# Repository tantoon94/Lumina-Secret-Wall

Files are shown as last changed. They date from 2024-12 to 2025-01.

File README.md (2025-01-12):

# Lumina-Secret-Wall
This project is designed for the [CASA0014 Connected Environments](https://github.com/ucl-casa-ce/casa0014) module to build an IoT device to control The [Chrono Lumina](https://github.com/ucl-casa-ce/casa0014/tree/main/chronoLumina) LED lights at CASA, UCL, through an MQTT broker. This Wall is an IoT device that can control the Chrono Lumina via six LDR sensors placed inside six projected hexagons. The nodes on each hexagon correspond to the placement of six LED numbers on Chrono Lumina. By Shedding light on any hexagon's LDR sensor (with any kind of flashlight), six corresponding LEDs will light up five showing the intensity of the flashlight using a gradient of cold to warm colours and one only white indicating a piece of code to decipher. The wall's final code could be deciphered by identifying the coloured LED numbers and putting them together in order. 

<p align="center">
The Fabricated Lumina wall
</p>

## Components

1. MCU Board (Arduino MKR 1010)
2. Sensors (LDR MJ5549)
7. Resistors (1kΩ for controlling the LDR sensitivity)
8. Breadboard (for prototyping)
9. Jumper Wires (male-to-male and male-to-female)
10 Power Supply (5V power supply is sufficient, Barrel Jack)

## Libraries
Make sure to include the following libraries in your Arduino IDE:

1. WiFiNINA
2. PubSubClient

## The project GuideMap

 The schematic model for devopling the device based on Chrono Lumina can be helpful in understanding the posisioning of the LEDs. Furthermore, it can be used to understand the Arrays defined in the code. To test the code without publishing to the broker, use the latest [Test](https://github.com/tantoon94/Lumina-Secret-Wall/blob/main/Arduino_Sketch/Test_sun_6pm/Test_sun_6pm.ino) version using the Arduino serial terminal to for debugging. 
<p align="center">
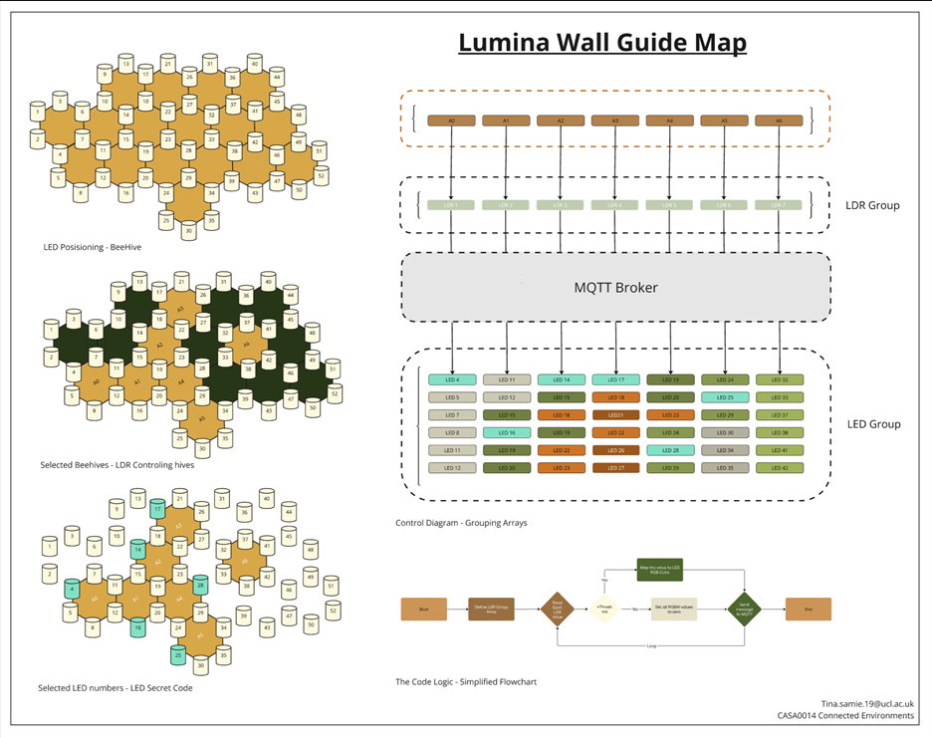
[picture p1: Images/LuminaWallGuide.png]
The Lumina Wall Guide

</p>

## Setup Instructions

### Circuit Connections:
1. **Power Supply:**
   - Connect the `3.3V` pin on the MKR 1010 to the positive rail on the breadboard.
   - Connect the `GND` pin on the MKR 1010 to the negative rail on the breadboard.

2. **LDR and Resistor Setup:**
   - For each LDR, connect one end to the positive rail (`3.3V`).
   - Connect the other end of each LDR to one end of a `10-ohm` resistor.
   - Connect the other end of each `10-ohm` resistor to the negative rail (`GND`).

3. **Analog Input Connections:**
   - Connect the junction between each LDR and its corresponding `10-ohm` resistor to an analog input pin on the MKR 1010 (e.g., `A0`, `A1`, `A2`, etc.).

<p align="center">
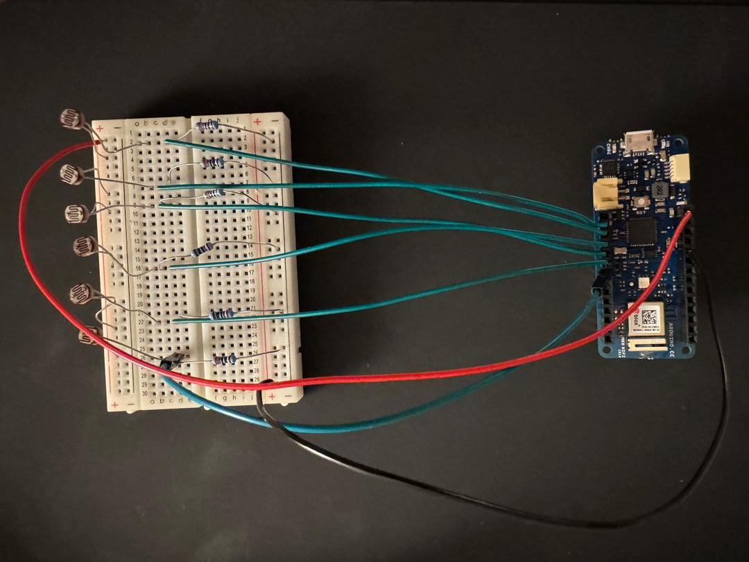
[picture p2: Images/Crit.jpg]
The Fabricated Lumina wall
  
</p>

### Design
 Using the [Model](https://github.com/tantoon94/Lumina-Secret-Wall/tree/main/MODEL) folder you can access the 3D models of the project. 
 The [G-code](https://github.com/tantoon94/Lumina-Secret-Wall/tree/main/MODEL/3Dprint/G-code) for the printing settings are available in the same directory. 

**MQTT Broker and LED Control:**
- Utilized an MQTT broker to publish instructions for controlling the color and on/off status of each LED pixel (12 pixels per LED string).
- Controlled 6 LEDs with one LDR using a matrix array to hold each LED number and their respective pixels.
- Managed simultaneous messages to shared LEDs, prioritizing messages where the threshold was crossed.
- Ensured LEDs turned off when below the threshold.
 
### Limitations 

**Sensor Calibration:**
- Calibrating sensors for varying light conditions was challenging.
- Using a `10Ω` resistor reduced the sensors' sensitivity, helping distinguish between environmental and flashlight light.
- Designed hexagon modular shapes with a three-pointed star crack to minimize environmental light while allowing sufficient flashlight light.
- Aimed to find the perfect balance between too much and too little light.

##  Contact Details

Tina Samie: tina.samie.19@ucl.ac.uk

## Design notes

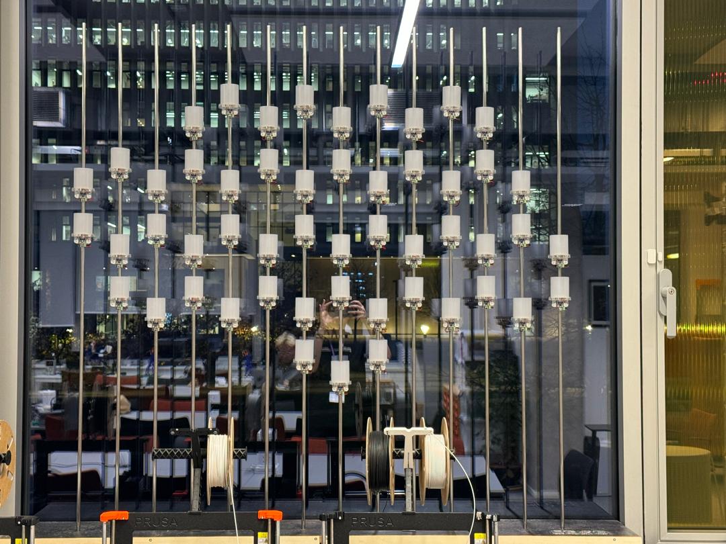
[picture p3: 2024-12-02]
Images/ChronoLumina.jpg

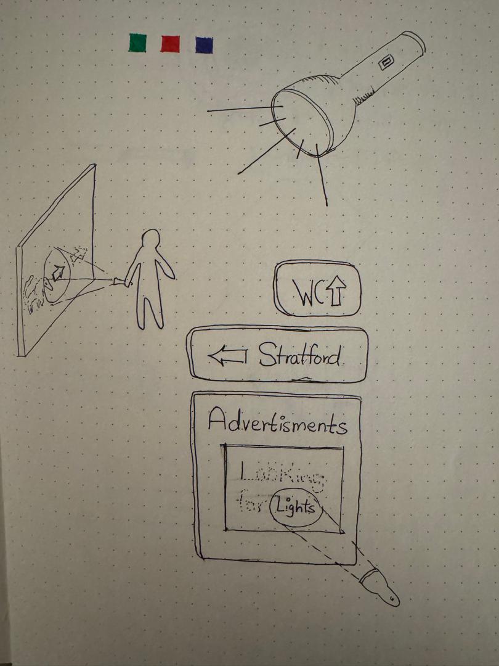
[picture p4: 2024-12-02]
Images/Sketch-Idea-1.jpg

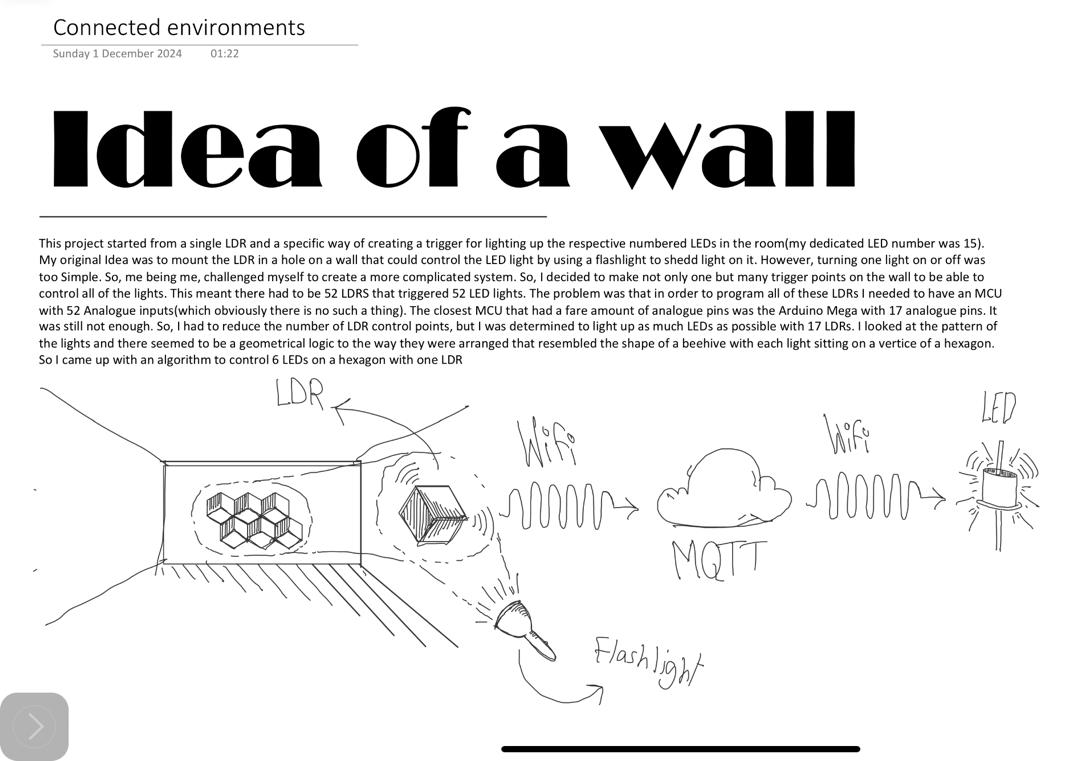
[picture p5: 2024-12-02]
Images/Sketch-Idea-2.jpg

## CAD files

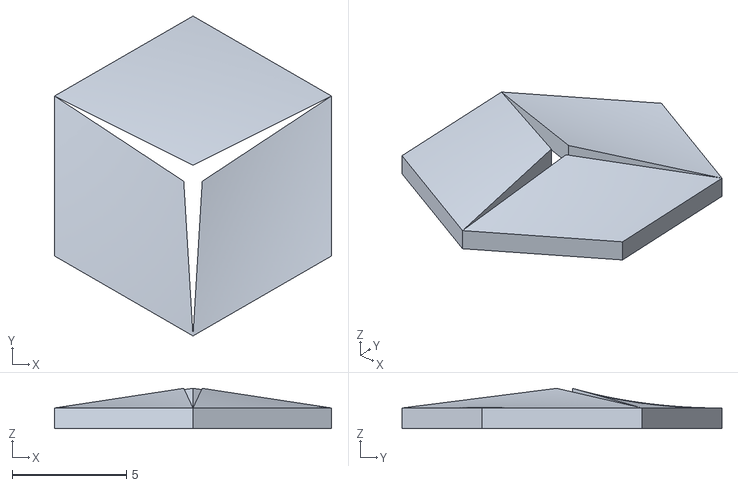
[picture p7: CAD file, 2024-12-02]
MODEL/3Dprint/Sample_02_mesh.stl
12.1 x 14.0 x 1.77

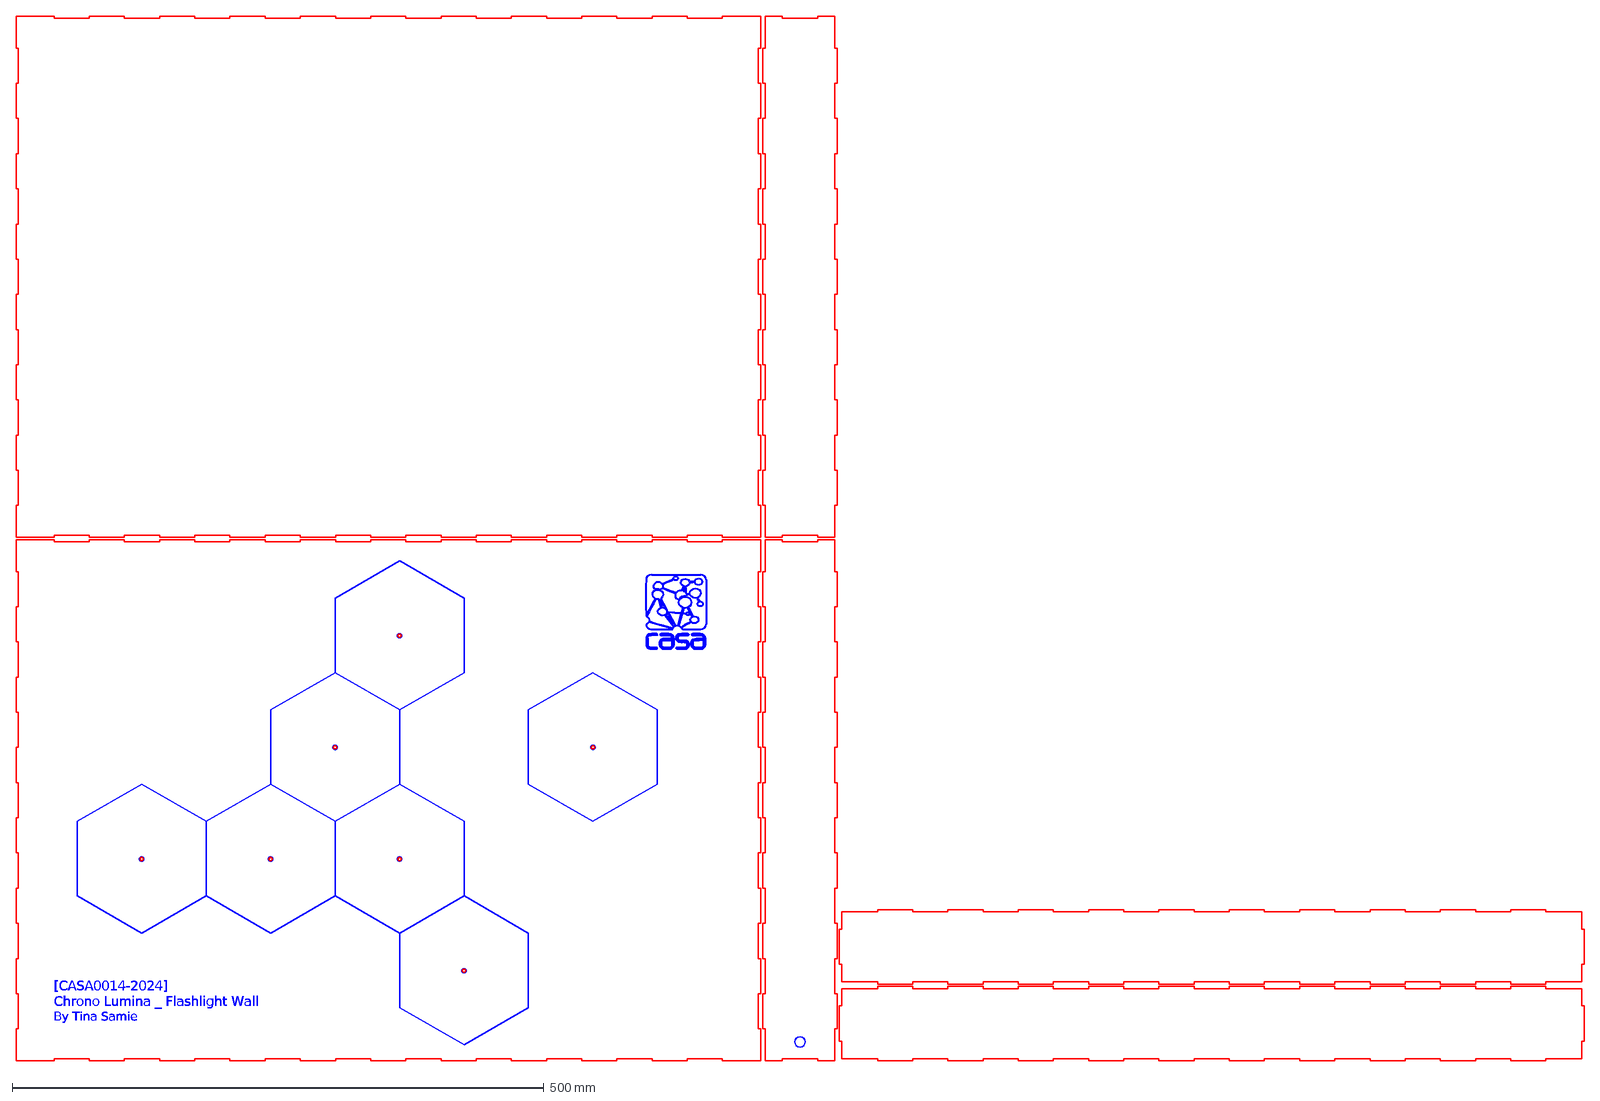
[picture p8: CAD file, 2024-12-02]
MODEL/Lasercut/Wall_Final_02.dxf
[CASA0014-2024] Chrono Lumina _ Flashlight Wall By Tina Samie

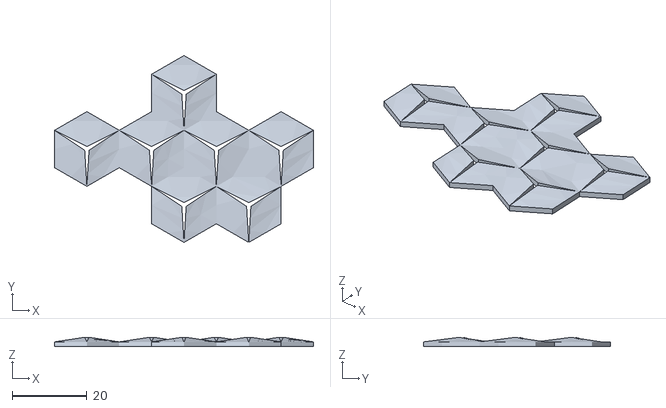
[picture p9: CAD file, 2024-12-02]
MODEL/3Dprint/6Hex.stl
69.3 x 50.0 x 2.52

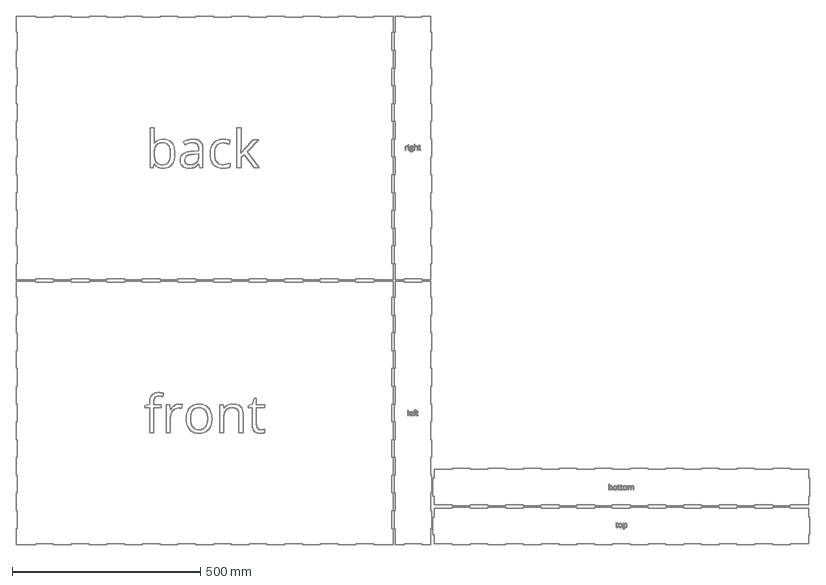
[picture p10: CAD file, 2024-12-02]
MODEL/Lasercut/box.dxf
2106.0 x 1403.0 mm

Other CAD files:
MODEL/3Dprint/6Hex.3dm

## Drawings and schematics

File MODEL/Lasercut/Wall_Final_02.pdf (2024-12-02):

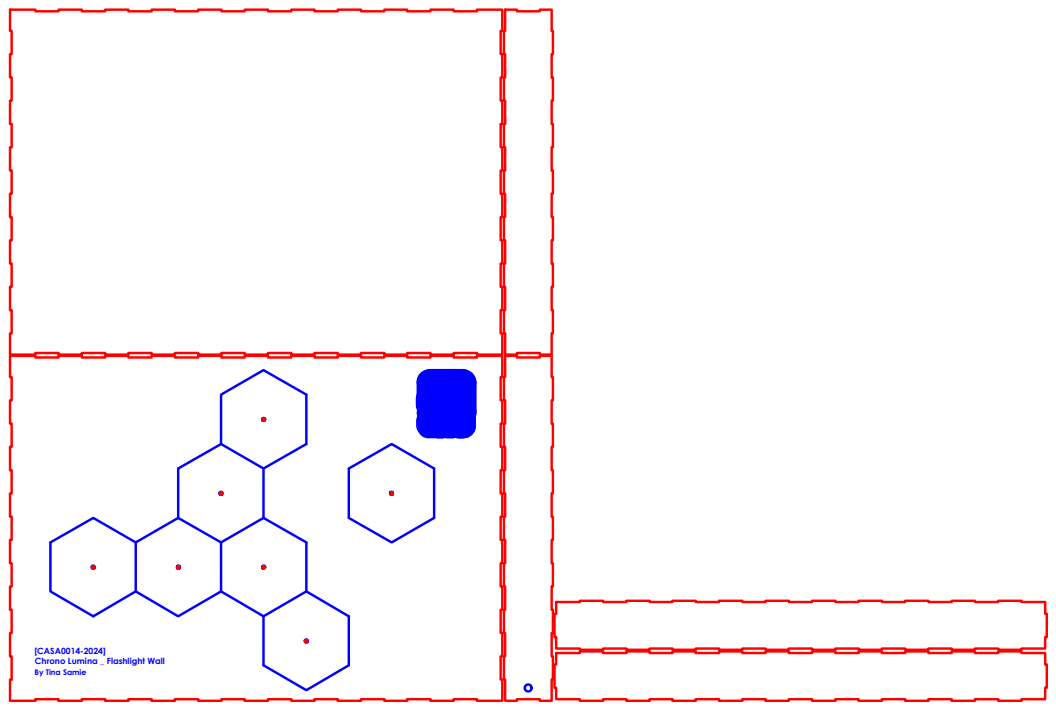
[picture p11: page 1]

[CASA0014-2024]
Chrono Lumina _ Flashlight Wall
By Tina Samie

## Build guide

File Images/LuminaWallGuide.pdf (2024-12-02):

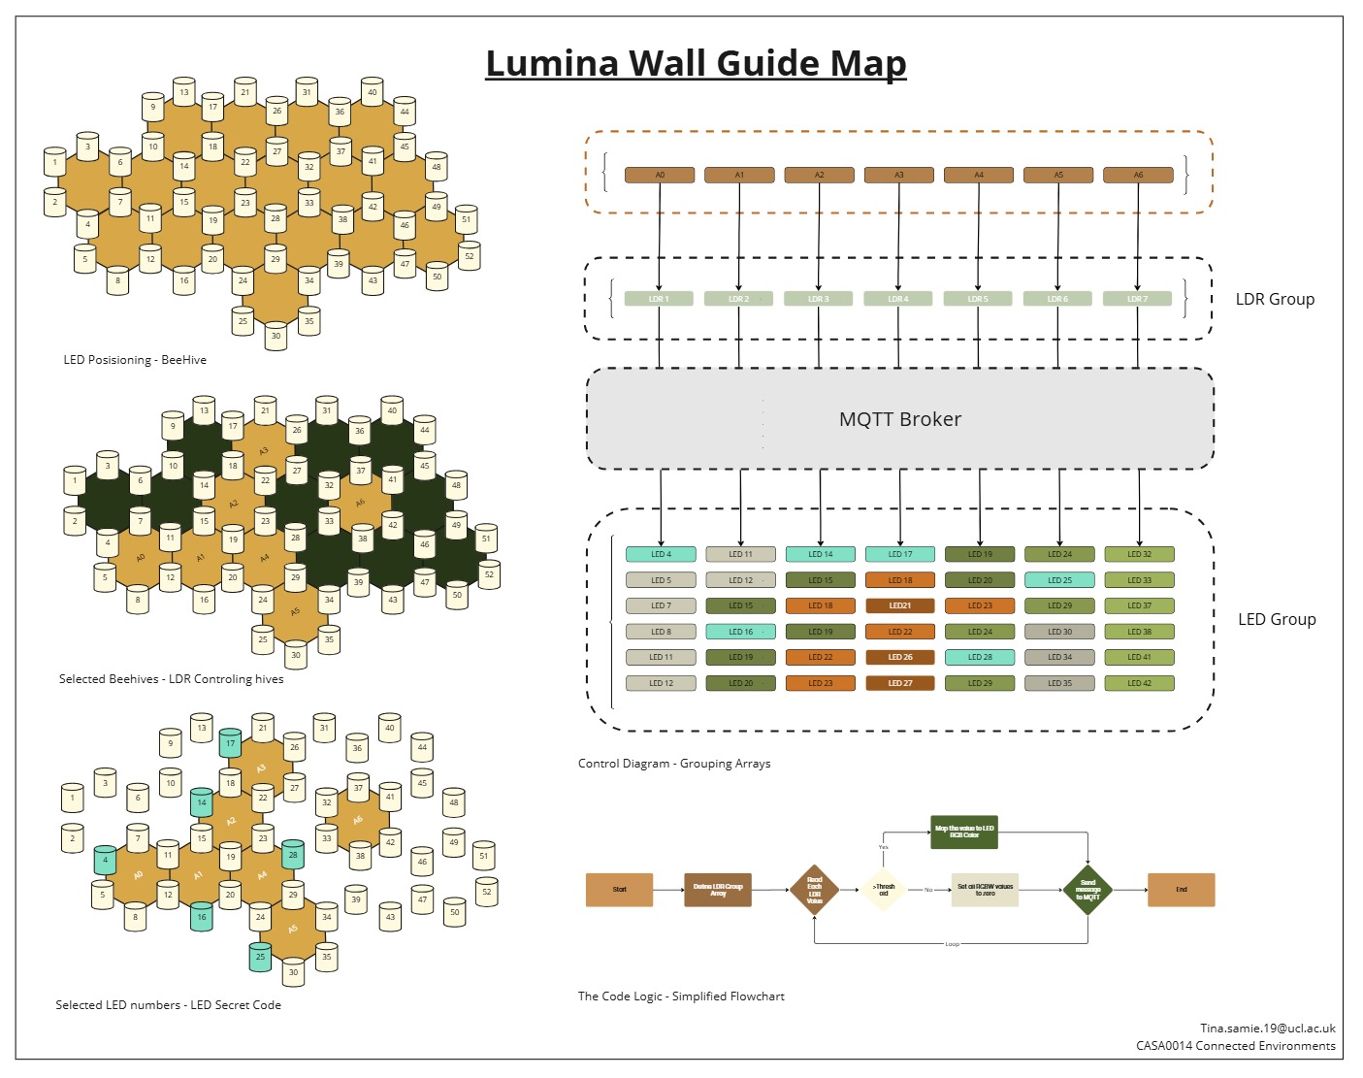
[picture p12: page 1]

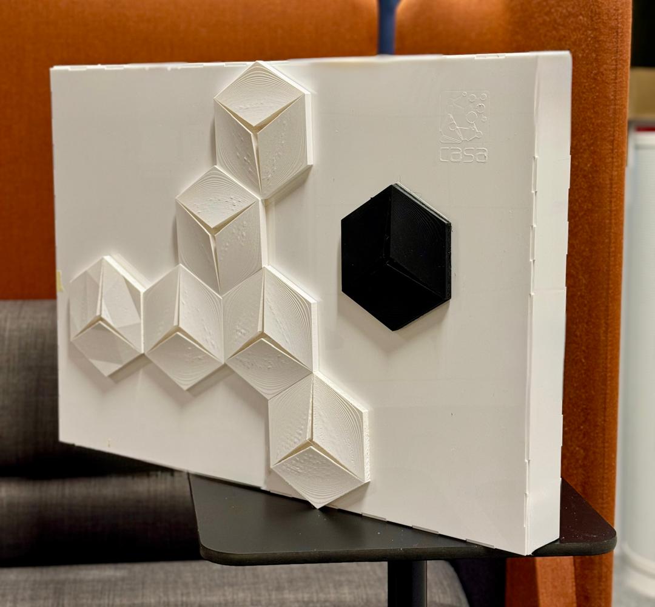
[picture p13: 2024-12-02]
Images/LuminaWall(Fabricated).jpg

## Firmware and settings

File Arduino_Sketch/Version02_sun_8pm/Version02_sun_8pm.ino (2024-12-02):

#include <WiFiNINA.h>
#include <PubSubClient.h>
#include "arduino_secrets.h"


const char* ssid          = SECRET_SSID;
const char* password      = SECRET_PASS;
const char* mqtt_username = SECRET_MQTTUSER;
const char* mqtt_password = SECRET_MQTTPASS;
const char* mqtt_server = "mqtt.cetools.org";
const int mqtt_port = 1884;
int status = WL_IDLE_STATUS;     // the Wifi radio's status

WiFiServer server(80);
WiFiClient wificlient;

WiFiClient mkrClient;
PubSubClient client(mkrClient);

const int numLDRs = 6;
const int threshold = 40; // here we define threshold value for LDRs
int ldrPins[numLDRs] = {A0, A1, A2, A3, A4, A5};
int ldrValues[numLDRs];
int ldrArrays[numLDRs][6] = {
    {4, 5, 7, 8, 11, 12},
    {11, 12, 15, 16, 19, 20},
    {14, 15, 18, 19, 22, 26},
    {17, 18, 21, 22, 26, 27},
    {19, 20, 23, 24, 28, 29},
    {24, 25, 29, 30, 34, 35}
};

void setup() {
  // Start the serial monitor to show output
  Serial.begin(115200);
  delay(1000);

  WiFi.setHostname("Lumina ucbqmie");
  startWifi();
  client.setServer(mqtt_server, mqtt_port);
  Serial.println("setup complete");
}

void loop() {
  // Ensure the Arduino is still connected to the MQTT broker
  if (!client.connected()) {
    reconnectMQTT();
  }

  // Ensure we are connected to the WiFi
  if (WiFi.status() != WL_CONNECTED) {
    startWifi();
  }

  // Check for messages from the broker and ensure outgoing messages are sent
  client.loop();

  sendmqtt();

  Serial.println("sent a message");
  delay(10000);
}

//building up the message
void sendmqtt() {
  char topic[50];
  char payload[100];

  //here I am defining the warm and cool effects of the lights by mapping the LDR values for each color 
  //the higher the number the more red value and less green and blue value

  for (int i = 0; i < numLDRs; i++) {
    if (ldrValues[i] > threshold) {
      int R = map(ldrValues[i], 20, 200, 0, 255);
      int G = map(ldrValues[i], 20, 200, 255, 0);
      int B = map(ldrValues[i], 20, 200, 255, 0);
      int W = 0; // Set white value to 0 

  //In this part we are constructing the Topic using the 2d array as ledvalue(the LED original numberings)

      for (int j = 0; j < 6; j++) {
        int ledValue = ldrArrays[i][j];
        sprintf(topic, "student/CASA0014/light/%d/pixel/", ledValue);
        Serial.println(topic);
        
        //next is to build up the mqtt messages as payloads:
        //first we are extracting some of the LEDs (ledValue) to have different messages from the rest
        //these chosen ones are going to be only white without any colors

        for (int k = 0; k <= 12; k++) {
          if (ledValue == 4 || ledValue == 14 || ledValue == 16 || ledValue == 17 || ledValue == 25 || ledValue == 28) {
            sprintf(payload, "{\"pixelid\": %d, \"R\": 0, \"G\": 0, \"B\": 0, \"W\": 60}", k);
          } else {
        
        //others are going to be as mapped ...
        
            sprintf(payload, "{\"pixelid\": %d, \"R\": %d, \"G\": %d, \"B\": %d, \"W\": %d}", k, R, G, B, W);
          }
          Serial.println(payload);
          client.publish(topic, payload);

            if (client.publish(mqtt_topic_demo, mqtt_message)) {
              Serial.println("Message published");
            } else {
              Serial.println("Failed to publish message");
            }
          }
        }
      }
    }
  } else {
    for (int j = 0; j < 6; j++) {
        int ledValue = ldrArrays[i][j];
        sprintf(topic, "student/CASA0014/light/%d/pixel/", ledValue);
        Serial.println(topic);
        for (int k = 0; k <= 12; k++) {
          sprintf(payload, "{\"pixelid\": %d, \"R\": 0, \"G\": 0, \"B\": 0, \"W\": 0}", k);
          Serial.println(payload);
          client.publish(topic, payload);
        }
  }
}

void startWifi() {
  // Check for the WiFi module
  if (WiFi.status() == WL_NO_MODULE) {
    Serial.println("Communication with WiFi module failed!");
    while (true); // Don't continue
  }
  String fv = WiFi.firmwareVersion();
  if (fv < WIFI_FIRMWARE_LATEST_VERSION) {
    Serial.println("Please upgrade the firmware");
  }

  // Function for connecting to a WiFi network
  // is looking for UCL_IoT and a back up network (usually a home one!)
  int n = WiFi.scanNetworks();
  Serial.println("Scan done");
  if (n == 0) {
    Serial.println("no networks found");
  } else {
    Serial.print(n);
    Serial.println(" networks found");
    // loop through all the networks and if you find UCL_IoT or the backup - ssid1
    // then connect to wifi
    Serial.print("Trying to connect to: ");
    Serial.println(ssid);
    for (int i = 0; i < n; ++i) {
      String availablessid = WiFi.SSID(i);
      // Primary network
      if (availablessid.equals(ssid)) {
        Serial.print("Connecting to ");
        Serial.println(ssid);
        WiFi.begin(ssid, password);
        while (WiFi.status() != WL_CONNECTED) {
          delay(600);
          Serial.print(".");
        }
        if (WiFi.status() == WL_CONNECTED) {
          Serial.println("Connected to " + String(ssid));
          break; // Exit the loop if connected
        } else {
          Serial.println("Failed to connect to " + String(ssid));
        }
      } else {
        Serial.print(availablessid);
        Serial.println(" - this network is not in my list");
      }
    }
  }

  Serial.println("");
  Serial.println("WiFi connected");
  Serial.print("IP address: ");
  Serial.println(WiFi.localIP());
}

void reconnectMQTT() {
  if (WiFi.status() != WL_CONNECTED) {
    startWifi();
  }

  // Loop until we're reconnected
  while (!client.connected()) {     // while not (!) connected....
    Serial.print("Attempting MQTT connection...");
    // Create a random client ID
    String clientId = "LuminaSelector";
    clientId += String(random(0xffff), HEX);

    // Attempt to connect
    if (client.connect(clientId.c_str(), mqtt_username, mqtt_password)) {
      Serial.println("connected");
      // ... and subscribe to messages on broker
    } else {
      Serial.print("failed, rc=");
      Serial.print(client.state());
      Serial.println(" try again in 5 seconds");
      // Wait 5 seconds before retrying
      delay(5000);
    }
  }
}

void callback(char* topic, byte* payload, int length) {
  // Handle incoming messages
  Serial.print("Message arrived [");
  Serial.print(topic);
  Serial.print("]: ");
  for (int i = 0; i < length; i++) {
    Serial.print((char)payload[i]);
  }
  Serial.println();
}

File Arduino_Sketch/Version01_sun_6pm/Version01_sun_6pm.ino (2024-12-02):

#include <WiFiNINA.h>
#include <PubSubClient.h>
#include "arduino_secrets.h"

// Our WiFi and MQTT credentials
const char* ssid          = "your_SSID";
const char* password      = "your_PASSWORD";
const char* mqtt_username = "your_MQTT_USERNAME";
const char* mqtt_password = "your_MQTT_PASSWORD";
const char* mqtt_server = "mqtt.cetools.org";
const int mqtt_port = 1884;
const char* wifiHostname = "Lumina_ucbqmie";

WiFiClient wifiClient;
PubSubClient client(wifiClient);

const int numLDRs = 6; 
const int threshold = 20; // threshold value for the LDRs
int ldrPins[numLDRs] = {A0, A1, A2, A3, A4, A5};
int ldrValues[numLDRs]; // this will hold an array of the values that will be read from each LDR
int ldrArrays[numLDRs][6] = { //this is a 2d array in which each row represents a group of LED numbers associated with a particular LDR.
    {4, 5, 7, 8, 11, 12},
    {11, 12, 15, 16, 19, 20},
    {14, 15, 18, 19, 22, 26},
    {17, 18, 21, 22, 26, 27},
    {19, 20, 23, 24, 28, 29},
    {24, 25, 29, 30, 34, 35}
};

void setup() {

  
  Serial.begin(115200);
  connectToWiFi();
  client.setServer(mqtt_server, mqtt_port);
  connectToMQTT();

  for (int i = 0; i < numLDRs; i++) { //defining each LDR as an Input
    pinMode(ldrPins[i], INPUT);
  }
}

void loop() {
  if (!client.connected()) {
    connectToMQTT();
  }
  client.loop();

  for (int i = 0; i < numLDRs; i++) {
    ldrValues[i] = analogRead(ldrPins[i]);
    ldrValues[i] = constrain(ldrValues[i], 20, 200); // Clamp values to the range 20-200
  }
  printLDRValues();
  printLDRStatus();
  publishLDRMessages();
  delay(1000); // Delay for readability
}

void connectToWiFi() {
  Serial.print("Connecting to ");
  Serial.println(ssid);
  WiFi.begin(ssid, password);
  WiFi.setHostname(wifiHostname);

  while (WiFi.status() != WL_CONNECTED) {
    delay(500);
    Serial.print(".");
  }
  Serial.println("Connected to WiFi");
}

void connectToMQTT() {
  while (!client.connected()) {
    Serial.print("Connecting to MQTT...");
    if (client.connect(wifiHostname, mqtt_username, mqtt_password)) {
      Serial.println("connected");
    } else {
      Serial.print("failed, rc=");
      Serial.print(client.state());
      Serial.println(" try again in 5 seconds");
      delay(5000);
    }
  }
}

void printLDRValues() {
  for (int i = 0; i < numLDRs; i++) {
    Serial.print("A");
    Serial.print(i);
    Serial.print(": ");
    Serial.print(ldrValues[i]);
    if (i < numLDRs - 1) {
      Serial.print(", ");
    }
  }
  Serial.println();
}

void printLDRStatus() {
  for (int i = 0; i < numLDRs; i++) {
    if (ldrValues[i] > threshold) {
      Serial.print("A");
      Serial.print(i);
      Serial.print(": ON");
    } else {
      Serial.print("A");
      Serial.print(i);
      Serial.print(": OFF");
    }
    if (i < numLDRs - 1) {
      Serial.print(", ");
    }
  }
  Serial.println();
}

void publishLDRMessages() {
  char topic[50];
  char payload[100];
  
  for (int i = 0; i < numLDRs; i++) {
    if (ldrValues[i] > threshold) {
      int R = map(ldrValues[i], 20, 200, 0, 255);
      int G = map(ldrValues[i], 20, 200, 255, 0);
      int B = map(ldrValues[i], 20, 200, 255, 0);
      int W = 100; // Set white value to 100
      for (int j = 0; j < 6; j++) {
        int ledValue = ldrArrays[i][j];
        sprintf(topic, "student/CASA0014/light/%d/pixel/", ledValue);
        Serial.println(topic);
        for (int k = 0; k <= 12; k++) {
          if (ledValue == 4 || ledValue == 14 || ledValue == 16 || ledValue == 17 || ledValue == 25 || ledValue == 28) {
            sprintf(payload, "{\"pixelid\": %d, \"R\": 0, \"G\": 0, \"B\": 0, \"W\": 60}", k);
          } else {
            sprintf(payload, "{\"pixelid\": %d, \"R\": %d, \"G\": %d, \"B\": %d, \"W\": %d}", k, R, G, B, W);
          }
          Serial.println(payload);
          client.publish(topic, payload);
        }
      }
    }
  }
}
